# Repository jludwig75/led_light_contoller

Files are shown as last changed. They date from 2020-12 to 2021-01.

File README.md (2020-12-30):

# LED Light Controller #
This is a simple controller for for cheap 2-wire LED strings. These strings are setup with LED's alternating polarity along the two wires. Current inone direction lights every other LED and current in the other direction lights the other LED's in the string. These LED strings are really cheap and often sold with remote controls to control the lighting. The battery life is terrible and the light patterns selections weren't that great. I wrote this Arduino sketch for and ESP8266 to control the LED strings. I am using ESP8266 breakouts from Electrodragon that include a USB port for programming and power. I am also using a DRV8833 H-bridge to controll the LED's powered by the 5V pin from the USB connector to the Electordragon board.

The sketch includes a web server used to controll the light pattern. Each board controls two strings (channels) independently. Note that the sketch is written to switch polarity every 10ms (100Hz). This allows the strings to appear to be contantly lit in both directions.

## Components  ##
- Electrodragon board link: https://www.electrodragon.com/product/esp8266-smd-adapter-breakout-board-r3/
- DRV8833 Link: https://www.amazon.com/gp/product/B08FJ3TX3Z/ref=ppx_yo_dt_b_asin_title_o01_s00?ie=UTF8&psc=1
- LED Light Strings: https://www.amazon.com/gp/product/B07QC65SZP/ref=ppx_yo_dt_b_asin_title_o04_s00?ie=UTF8&psc=1

## Schematic ##
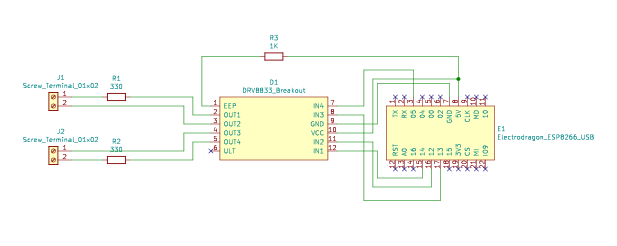
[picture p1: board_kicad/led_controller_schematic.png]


## PCB Board ##
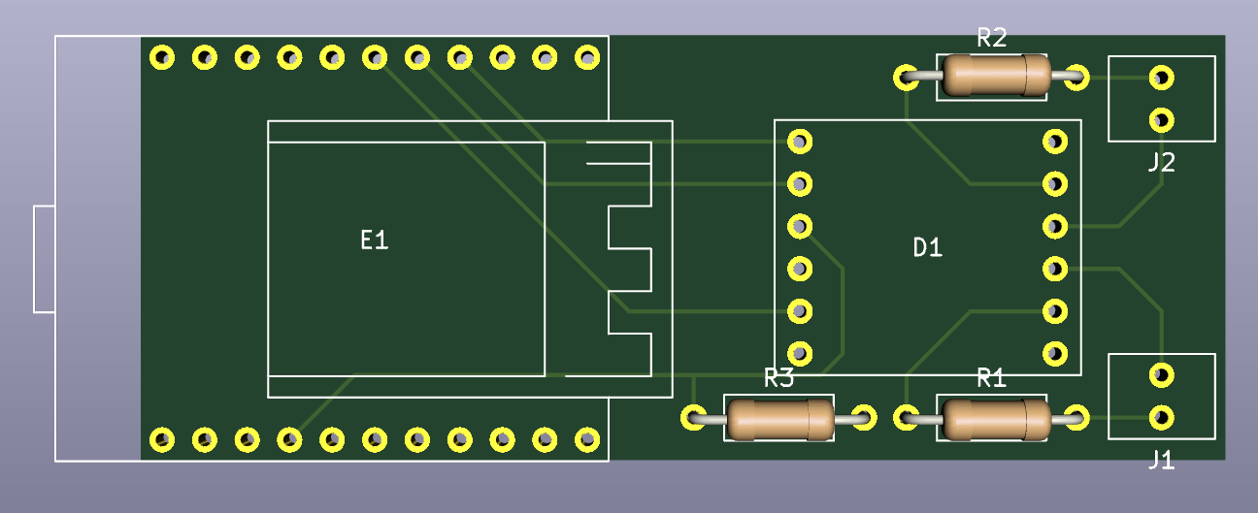
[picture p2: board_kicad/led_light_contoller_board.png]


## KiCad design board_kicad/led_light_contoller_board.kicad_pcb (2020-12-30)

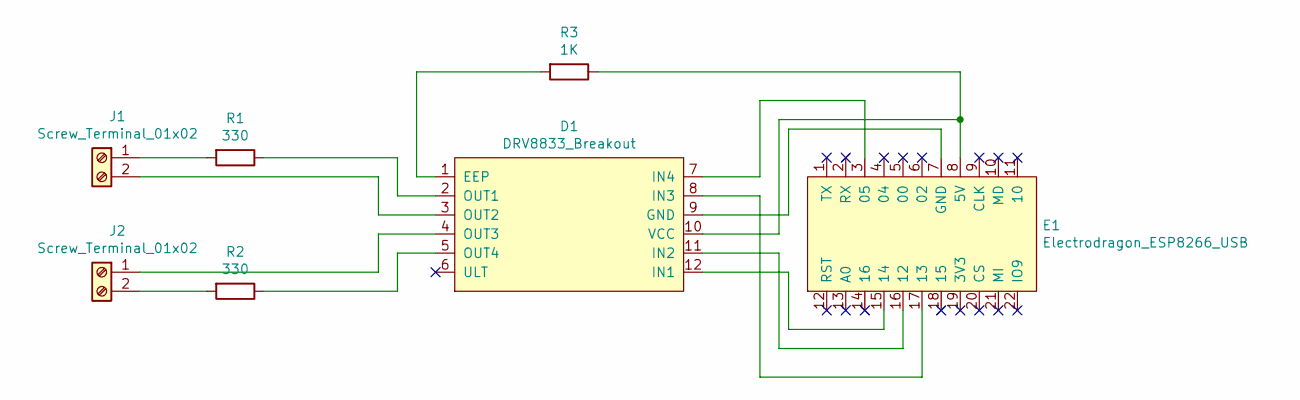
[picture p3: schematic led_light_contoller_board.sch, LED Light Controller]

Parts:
D1: DRV8833_Breakout
E1: Electrodragon_ESP8266_USB; Electrodragon ESP8266 USB
J1, J2: Screw_Terminal_01x02; Screw_Terminal_2.54mm
R1, R2: 330; R_Axial_DIN0207_L6.3mm_D2.5mm_P10.16mm_Horizontal
R3: 1K; R_Axial_DIN0207_L6.3mm_D2.5mm_P10.16mm_Horizontal

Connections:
unnamed: D1.1 (EEP), R3.2
unnamed: D1.2 (OUT1), R1.1
unnamed: D1.3 (OUT2), J1.2
unnamed: D1.4 (OUT3), J2.1
unnamed: D1.5 (OUT4), R2.1
unnamed: D1.7 (IN4), E1.3 (05)
unnamed: D1.8 (IN3), E1.17 (13)
unnamed: D1.9 (GND), E1.7 (GND)
unnamed: D1.10 (VCC), E1.8 (5V), R3.1
unnamed: D1.11 (IN2), E1.16 (12)
unnamed: D1.12 (IN1), E1.15 (14)
unnamed: J1.1, R1.2
unnamed: J2.2, R2.2

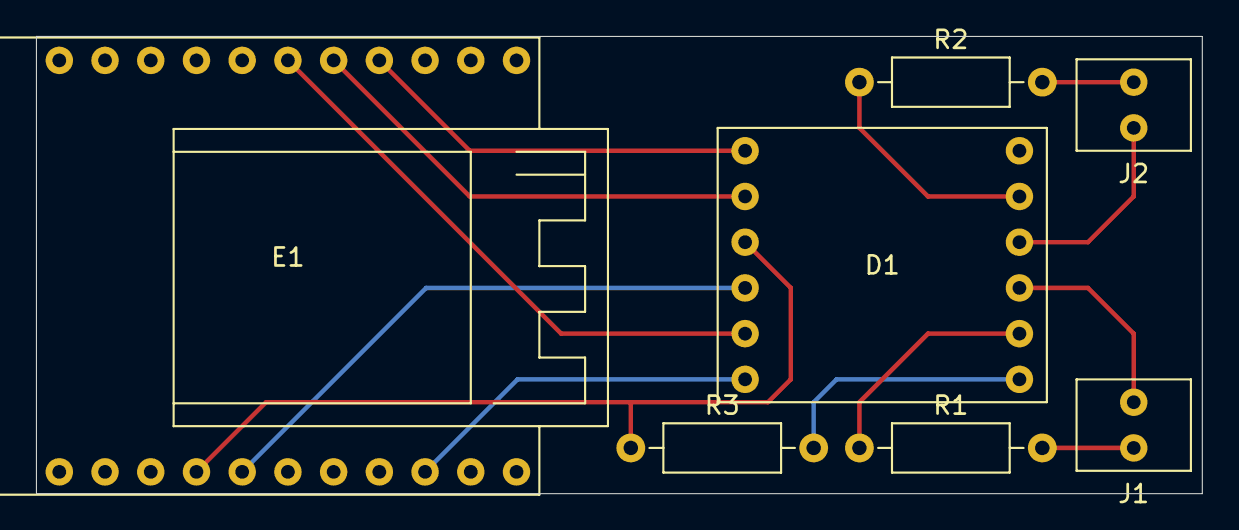
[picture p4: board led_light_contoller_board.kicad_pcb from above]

Board: 2 copper layers, 64.8 x 25.4 mm, 7 parts (0 on the bottom side), 13 nets.

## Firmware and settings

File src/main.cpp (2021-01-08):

#include <Arduino.h>
#include <BasicOTA.h>
#include <BasicWifi.h>

#include "ledcontroller.h"
#include "webserver.h"
#include "filesystem.h"

/* NOTE: please add this file (config.h) and define the following in it:
const char* ssid = "SSID Name";
const char* password = "SSID Passwod";
const char* otaPassword = "Desired OTA password";
const uint8_t CHANNEL1_PIN1 = 1;
const uint8_t CHANNEL1_PIN2 = 2;
const uint8_t CHANNEL2_PIN1 = 3;
const uint8_t CHANNEL2_PIN2 = 4;
*/
#include "config.h" // <= This file is not part of the repo code. You must add it. See above. ^^^


LedController controller(CHANNEL1_PIN1,
                         CHANNEL1_PIN2,
                         CHANNEL2_PIN1,
                         CHANNEL2_PIN2);

WebServer webServer(controller);

void setup()
{
    Serial.begin(115200);
    delay(50);
    fileSystem_setup();
    controller.begin();

    wifi_setup(HOST_NAME, ssid, password);
    ota_setup(HOST_NAME, otaPassword);
    webServer.begin();
}

void loop()
{
    controller.onLoop();
    ota_onLoop();
    webServer.onLoop();
    wifi_onLoop();
}

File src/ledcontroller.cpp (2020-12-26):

#include "ledcontroller.h"

#include <Arduino.h>

LedController::LedController(uint8_t channel1Pin1,
                             uint8_t channel1Pin2,
                             uint8_t channel2Pin1,
                             uint8_t channel2Pin2)
    :
    _channels{ LedChannel(1, channel1Pin1, channel1Pin2),
               LedChannel(2, channel2Pin1, channel2Pin2) }
{
}

void LedController::begin()
{
    for (auto& channel : _channels)
    {
        channel.begin();
    }
}

void LedController::onLoop()
{
    static unsigned long lastMillisInterval = 0;
    auto interval = millis() / 10;
    if (interval != lastMillisInterval)
    {
        LedChannel::onTimerInterval();
        lastMillisInterval = interval;
    }
    for (auto& channel : _channels)
    {
        channel.onLoop();
    }
}


std::vector<LedChannel>& LedController::channels()
{
    return _channels;
}

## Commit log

2020-12-25 Started basic framework for board firmware
2020-12-25 Got webserver working with mock LED channels
2020-12-25 LED controller and channel
2020-12-25 Set default mode to constant. Don't show any mode in UI if change mode failed
    [ledchannel.cpp]
2020-12-25 Improved button appearance
2020-12-25 Use jQuery UI for better radio buttons
2020-12-25 Left align text on radio buttons
2020-12-25 Don't reinvent the wheel. Fix webpage title
2020-12-26 Set initial LED string state
2020-12-26 Got bidirectional LED signal working
    Had to disable web page refresh because it perturbs the timer.
    Need to get some kind of HW timer working, but it is REALLY touchy.
    Maybe adding a 3v3 arduino mini might be better and it can implement
    the timer and drive the H bridge.
2020-12-28 Swith terminology from direction to stripe. Issue #2
    [ledchannel.cpp, ledstring.cpp]
2020-12-28 Persist channel mode to flash. Issue #4
    [ledchannel.cpp, main.cpp]
2020-12-28 Separated side 0 and 1 brightness levels. Made string functions return separate side brightness levels. Fixes issue #1
    [ledchannel.cpp, ledstring.cpp]
2020-12-30 Added schematic and PCB to project
    [led_light_contoller_board.kicad_pcb, led_light_contoller_board.sch]
